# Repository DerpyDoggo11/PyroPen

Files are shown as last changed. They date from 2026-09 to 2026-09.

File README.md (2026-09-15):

# Pyropen
A pen with an embedded charlieplexed screen and thermal sensor

## 3D Model Preview
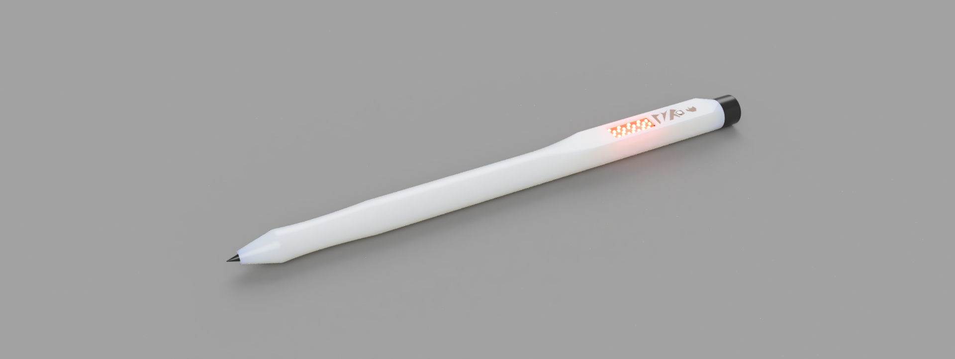
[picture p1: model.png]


## 3D PCB Preview
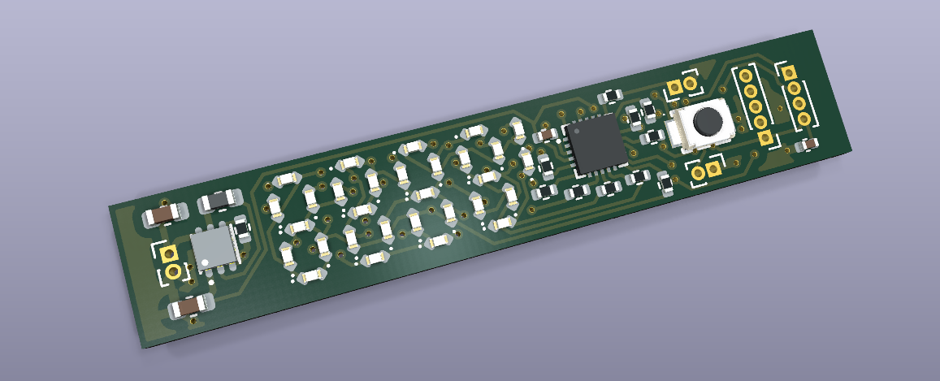
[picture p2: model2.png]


## Wiring
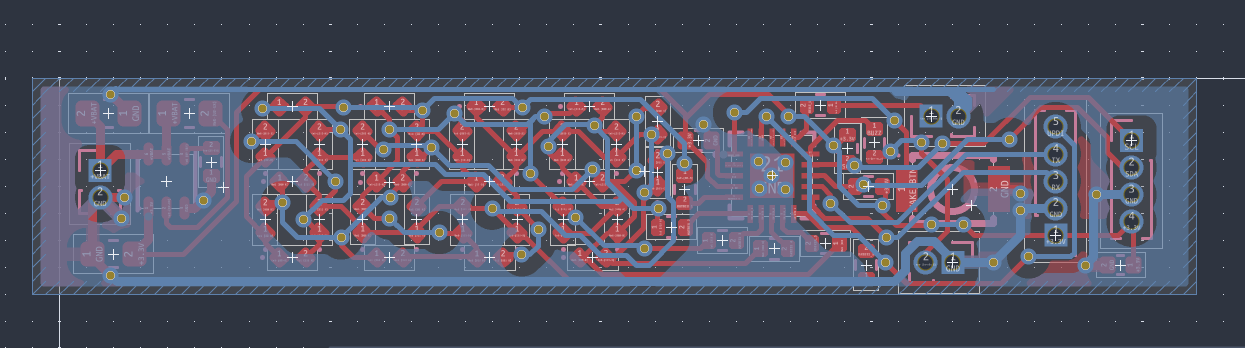
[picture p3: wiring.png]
PCB


## Schematic
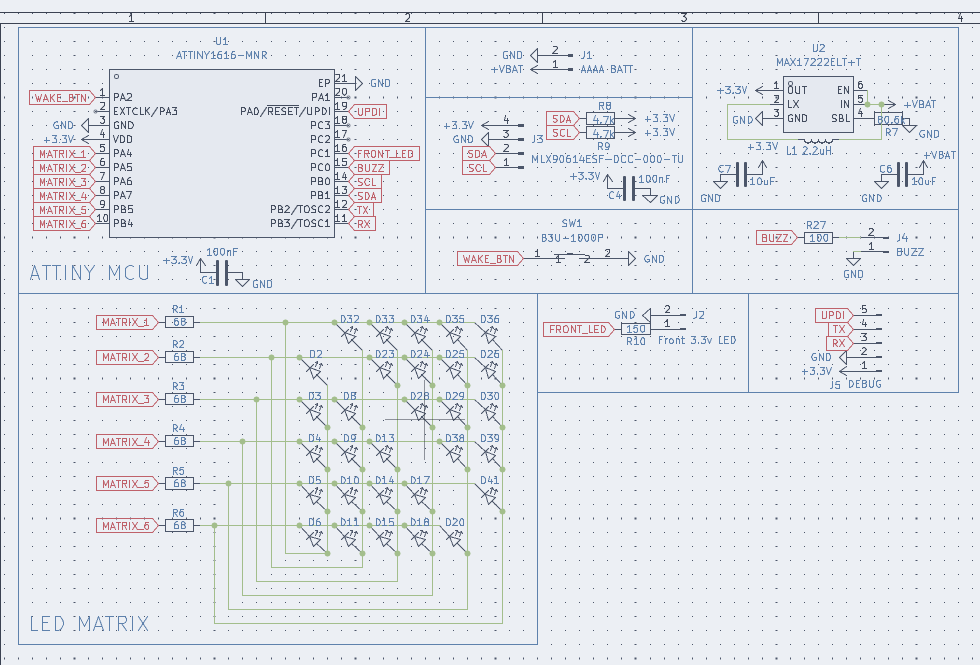
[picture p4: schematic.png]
Schematic


## Introduction
Hobby electronics projects can come with a lot of dangers, especially if there is a short between ground and the main voltage line (3.3v) through a component, which is one of the most common faults when hand soldering. These components can get really hot which means placing your finger to sense the temperature is not a super safe option, and is also not very possible for really small components in tight areas. Theres also hundreds of other applications like seeing if a soldering iron is at the good temperature or if something is being heated properly where touching it is not very recommended... 

My solution to this is the PyroPen - a portable thermal sensor that fits in the palm of your hand! It can also replace a regular pen, meaning that you have this sensor on you wherever you go. 

## Bill of Materials 

### 5 Pens:

| Quantity | Components | Price | Link |
|--- |---|---| -----|
| 5  | D1 Mini Pen Refill  (around 67mm long) | $6 | [here](https://www.aliexpress.us/item/3256810502408645.html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)
| 1 | Plexiglass sheet | $5 | [here](https://www.aliexpress.us/item/3256807722386926.html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)
| 1 | M10 tap and M10 die | $10-25 | [here](https://www.aliexpress.us/item/3256806490105856.html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)
| 1 | Black Silicone Sheet | $6 | [here](https://www.aliexpress.us/item/3256803477740534.html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)
| 10 | Contact Springs | $3 | [here](https://www.aliexpress.us/item/3256811981198202.html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) 
| 5 | 5mm Piezoelectric Buzzers | $1 | [here](https://www.lcsc.com/product-detail/C76871.html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) 
| 5 | MLX Infrared Sensors | $44 | [here](https://www.lcsc.com/product-detail/C3663116.html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)
| 5 | AAAA Batteries | $7 | [here](https://www.amazon.com/AmazonBasics-Everyday-Alkaline-Batteries-8-Pack/dp/B00LH3DTYS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)
| 5 | Warm Leds | $1 | [here](https://www.lcsc.com/product-detail/C5440675.html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) 
| 5 | PCBA for PyroPen | $60 | Uploaded PCB fabrication files to JLCPCB and assemble it. 
 
Total cost: **$157**

Cost per pen: **$31.4**

----

## Tools / Other parts:
- M10 Tap and Die (from BOM)
- Hot glue + hot glue gun (or super glue)
- Dremel
- Raspbbery Pi, or any other device that can be used to flash firmware to the ATTINY chip.
- 3D printer

## Assembly
1. 3D print the case and assembly 
2. Use the M10 Tap and Die to thread the three pieces at their corresponding places
3. Cut plexiglass and glue onto the screen case
4. Remove the tabs from the PCB with a dremel (required for meeting the PCBA size requirements)
5. Flash firmware to the PCB with a raspbbery pi (or other method)
6. Solder on the buzzer, MLX sensor, and contact springs to the PCB
7. Insert the assembly into the case.
8. Glue the PCB to the inside of the case with the screen facing out and the button in place
9. Insert the pen refill tightly into the case
10. Mount the remaining components into the case, insert battery, and seal

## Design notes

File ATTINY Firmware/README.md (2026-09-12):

# PyroPen firmware

C++ / PlatformIO firmware for the PyroPen — a pen-format non-contact IR
thermometer built around an **ATtiny1616** (tinyAVR 1-series).

## What it does
- Reads object temperature from the **MLX90614** IR sensor over I²C.
- Displays it as a left→right **bar** on the 30-LED charlieplexed panel
  (range `25–250 °C`, configurable in `src/main.cpp`).
- Warns when the target is hot (≥ 45 °C): lights the **front LED** and beeps.
- **Button** (PA2): short press toggles °C/°F, long press (≥0.8 s) mutes the buzzer.
- Prints readings on the serial port (115200 baud, TX=PB2).
- Runs a startup LED sweep so you can verify every dot after assembly.

## Pin map (from the KiCad netlist)
| Function | MCU pin(s) |
|---|---|
| Charlieplex rails | PA4 PA5 PA6 PA7 PB5 PB4 |
| I²C (MLX90614) | SDA=PB1, SCL=PB0 (addr 0x5A) |
| Buzzer (BTL) | PC1 + PC0 (anti-phase) |
| Front LED | PC2 |
| Button | PA2 (active-low, pullup) |
| Serial debug | TX=PB2, RX=PB3 |
| UPDI (program) | PA0 |

## Build & flash
The board is programmed over **UPDI** (single wire), not ISP/SPI. Any
serial-UPDI adapter works, including a **Raspberry Pi**.

### Wiring the programmer to the DEBUG header (J5, 1.0 mm pitch)
J5 pinout: `1=UPDI  2=GND  3=RX  4=TX  5=+3.3V` — check pins 4/5 on the board
before powering. For flashing you only need UPDI + GND (+ 3.3V if the pen
isn't otherwise powered).

Classic serial-UPDI adapter (USB-serial or Pi UART):
```
  TX ──[1 kΩ]──┬── UPDI (J5.1)
  RX ──────────┘
  GND ── GND (J5.2)
```

### Set your port, then upload
Edit `upload_port` in `platformio.ini`:
- Raspberry Pi GPIO UART: `/dev/serial0` (enable UART, disable the serial console)
- USB-serial on Linux: `/dev/ttyUSB0`
- Windows: `COM4`

```bash
pio run                 # build
pio run -t upload       # flash over UPDI
pio device monitor      # 115200 baud
```

## Notes
- Clock is the **10 MHz** internal oscillator: at 3.3 V (MAX17222 boost) the
  part is not rated for 20 MHz. Change `board_build.f_cpu` only if you raise Vcc.
- The buzzer is bridge-tied across PC0/PC1; the `beep()` routine drives them
  anti-phase for a louder tone. This is why the standard Arduino `tone()` isn't
  used (it drives a single pin).
- Display multiplexing is cooperative (in `loop()`), so no hardware timer is
  claimed and it can't collide with `millis()`/`tone()`.

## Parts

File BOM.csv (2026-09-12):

Item | Quantity | Component | Price | Link
1 | 5 | D1 Mini Pen Refill (around 67mm long) | $6 | https://www.aliexpress.us/item/3256810502408645.html
2 | 1 | Plexiglass sheet | $5 | https://www.aliexpress.us/item/3256807722386926.html
3 | 1 | M10 tap and M10 die | $10-25 | https://www.aliexpress.us/item/3256806490105856.html
4 | 1 | Black Silicone Sheet | $6 | https://www.aliexpress.us/item/3256803477740534.html
5 | 10 | Contact Springs | $3 | https://www.aliexpress.us/item/3256811981198202.html
6 | 5 | 5mm Piezoelectric Buzzers | $1 | https://www.lcsc.com/product-detail/C76871.html
7 | 5 | MLX Infrared Sensors | $44 | https://www.lcsc.com/product-detail/C3663116.html
8 | 5 | PCBA for PyroPen | $80

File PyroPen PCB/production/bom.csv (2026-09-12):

Designator | Footprint | Quantity | Value | LCSC Part #
C1, C4 | 0402 | 2 | 100nF
C6, C7 | 0603 | 2 | 10uF
D10, D11, D13, D14, D15, D17, D18, D2, D20, D23, D24, D25, D26, D28, D29, D3, D30, D32, D33, D34, D35, D36, D38, D39, D4, D41, D5, D6, D8, D9 | 0402 | 30 | LED_45deg
J1 | PinHeader_1x02_P1.00mm_Vertical | 1 | AAAA BATT
J2 | PinHeader_1x02_P1.00mm_Vertical | 1 | Front 3.3v LED
J3 | PinHeader_1x04_P1.00mm_Vertical | 1 | MLX90614ESF-DCC-000-TU
J4 | PinHeader_1x02_P1.00mm_Vertical | 1 | BUZZ
J5 | PinHeader_1x05_P1.00mm_Vertical | 1 | DEBUG
L1 | 0603 | 1 | 2.2uH
R1, R2, R3, R4, R5, R6 | 0402 | 6 | 68
R10 | 0402 | 1 | 150
R27, R28 | 0402 | 2 | 100
R7 | 0402 | 1 | 80.6k
R8, R9 | 0402 | 2 | 4.7k
SW1 | KEY-SMD_B3U-1000PM | 1 | B3U-1000P | C231329
U1 | QFN-20_L3.0-W3.0-P0.40-BL-EP1.7 | 1 | ATTINY1616-MNR | C507118
U2 | TDFN-6_L2.0-W2.0-P0.65-BL | 1 | MAX17222ELT+T | C1121854

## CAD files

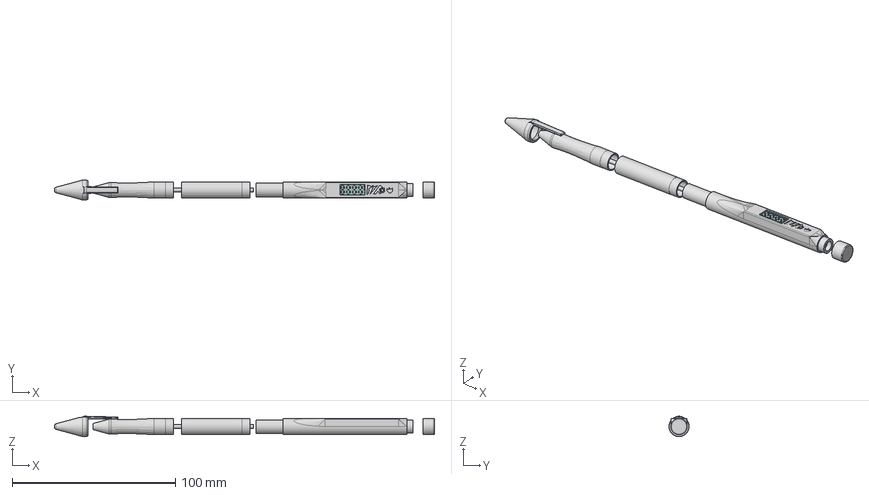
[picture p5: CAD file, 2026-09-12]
3D Case/pyropen-case.step
233.0 x 12.4 x 12.6 mm
LED_0402_1005Metric x 30
R_0402_1005Metric x 11
KEY-SMD_2P-L3.0-W2.5-H1.6-LS4.0
L_0603_1608Metric
TDFN-6_L2.0-W2.0-H0.8-P0.65-BL
QFN-20_L3.0-W3.0-P0.40-BL-EP1.7
C_0603_1608Metric x 2
C_0402_1005Metric x 2
AAAA Battery
Sensor

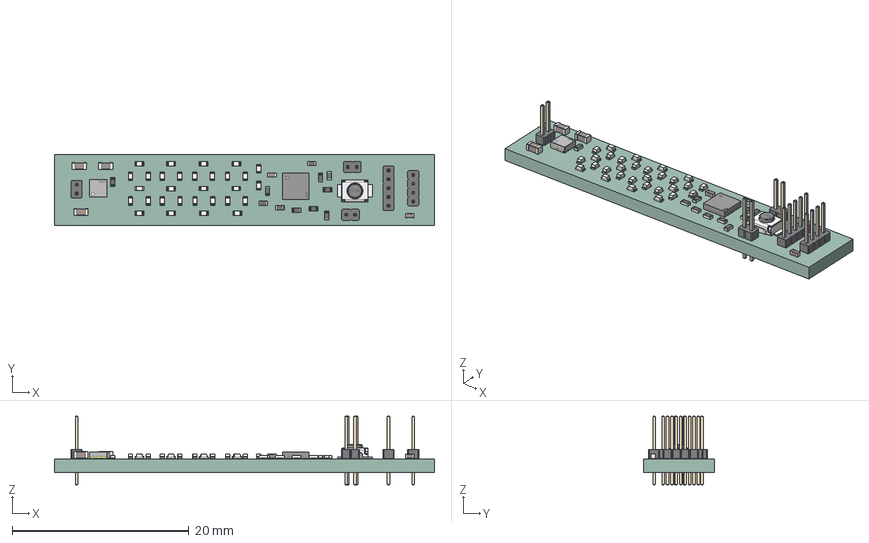
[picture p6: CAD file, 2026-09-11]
PyroPen PCB/pyropen.step
43.0 x 8.00 x 7.80 mm
LED_0402_1005Metric x 30
R_0402_1005Metric x 11
L_0603_1608Metric
TDFN-6_L2.0-W2.0-H0.8-P0.65-BL
PinHeader_1x02_P1.00mm_Vertical x 3
KEY-SMD_2P-L3.0-W2.5-H1.6-LS4.0
QFN-20_L3.0-W3.0-P0.40-BL-EP1.7
C_0402_1005Metric x 2
C_0603_1608Metric x 2
PinHeader_1x04_P1.00mm_Vertical
PinHeader_1x05_P1.00mm_Vertical
pyropen_PCB

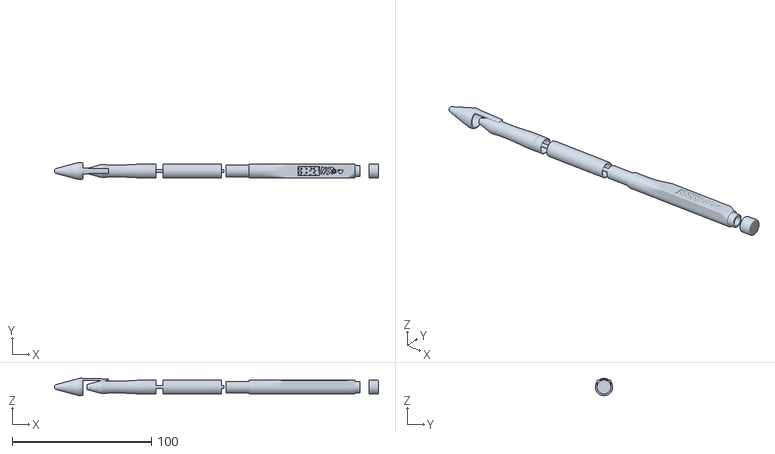
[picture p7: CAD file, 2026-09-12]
3D Case/pyropen.stl
233.0 x 12.5 x 12.6

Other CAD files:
3D Case/pyropen.f3d

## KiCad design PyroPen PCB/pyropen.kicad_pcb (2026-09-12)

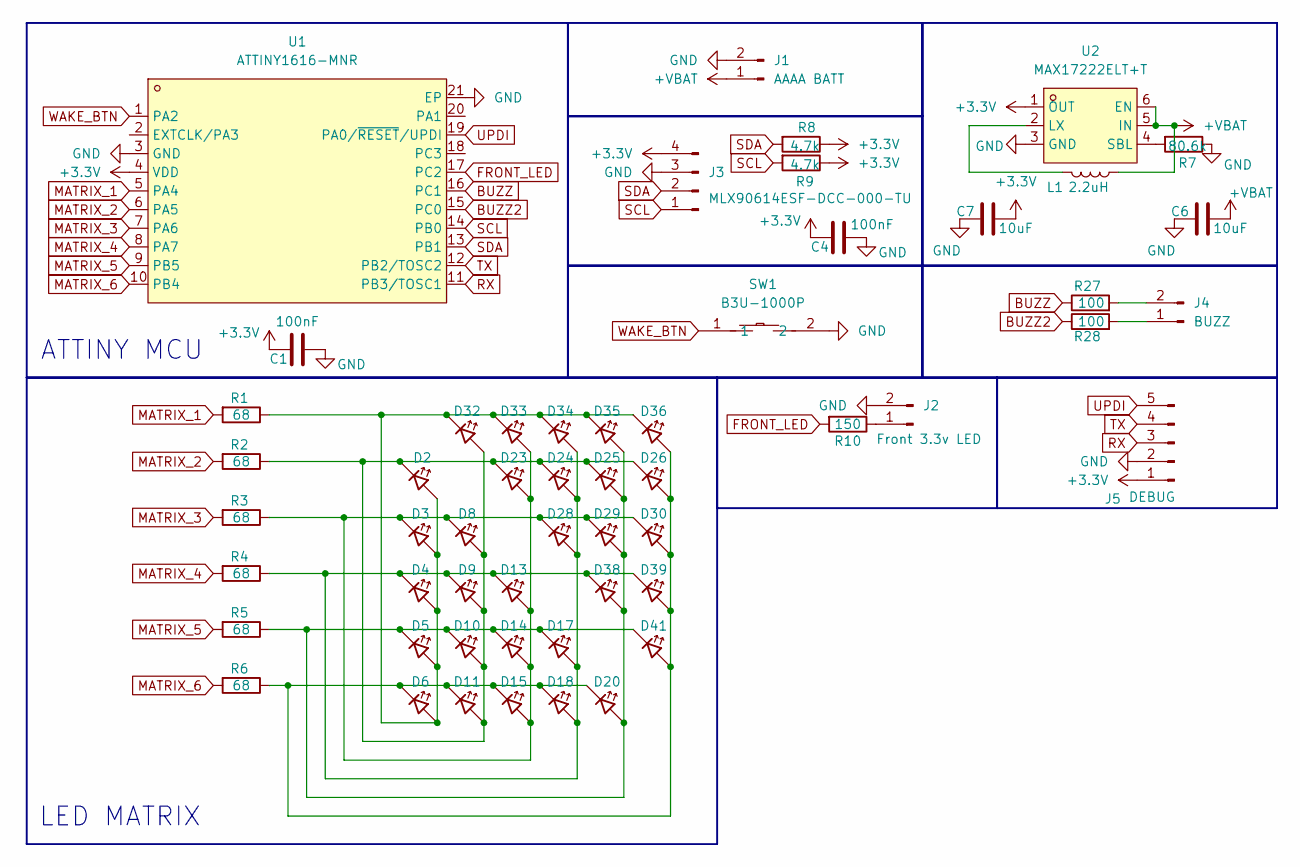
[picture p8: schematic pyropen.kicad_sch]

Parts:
C1, C4: 100nF; C_0402_1005Metric
C6, C7: 10uF; C_0603_1608Metric
D2, D3, D4, D5, D6, D8, D9, D10, D11, D13, D14, D15, D17, D18, D20, D23, D24, D25, D26, D28, D29, D30, D32, D33, D34, D35, D36, D38, D39, D41: LED_45deg; LED_0402_1005Metric
J1: AAAA BATT; PinHeader_1x02_P1.00mm_Vertical
J2: Front 3.3v LED; PinHeader_1x02_P1.00mm_Vertical
J3: MLX90614ESF-DCC-000-TU; PinHeader_1x04_P1.00mm_Vertical
J4: BUZZ; PinHeader_1x02_P1.00mm_Vertical
J5: DEBUG; PinHeader_1x05_P1.00mm_Vertical
L1: 2.2uH; L_0603_1608Metric
R1, R2, R3, R4, R5, R6: 68; R_0402_1005Metric
R7: 80.6k; R_0402_1005Metric
R8, R9: 4.7k; R_0402_1005Metric
R10: 150; R_0402_1005Metric
R27, R28: 100; R_0402_1005Metric
SW1: B3U-1000P; KEY-SMD_B3U-1000PM; MPN B3U-1000P; LCSC Part C231329
U1: ATTINY1616-MNR; QFN-20_L3.0-W3.0-P0.40-BL-EP1.7; MPN ATTINY1616-MNR; LCSC Part C507118
U2: MAX17222ELT+T; TDFN-6_L2.0-W2.0-P0.65-BL; MPN MAX17222ELT+T; LCSC Part C1121854

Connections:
+3.3V: C1.1, C4.1, C7.2, J3.4, J5.1, R8.1, R9.1, U1.4 (VDD), U2.1 (OUT)
+VBAT: C6.2, J1.1, L1.1, U2.5 (IN), U2.6 (EN)
BUZZ: R27.1, U1.16 (PC1)
BUZZ2: R28.1, U1.15 (PC0)
FRONT_LED: R10.2, U1.17 (PC2)
GND: C1.2, C4.2, C6.1, C7.1, J1.2, J2.2, J3.3, J5.2, R7.1, SW1.2, U1.3 (GND), U1.21 (EP), U2.3 (GND)
MATRIX_1: R1.2, U1.5 (PA4)
MATRIX_2: R2.2, U1.6 (PA5)
MATRIX_3: R3.2, U1.7 (PA6)
MATRIX_4: R4.2, U1.8 (PA7)
MATRIX_5: R5.2, U1.9 (PB5)
MATRIX_6: R6.2, U1.10 (PB4)
unnamed: D2.2 (A), D3.2 (A), D4.2 (A), D5.2 (A), D6.2 (A), D32.1 (K), D33.1 (K), D34.1 (K), D35.1 (K), D36.1 (K), R1.1
unnamed: D2.1 (K), D8.2 (A), D9.2 (A), D10.2 (A), D11.2 (A), D23.1 (K), D24.1 (K), D25.1 (K), D26.1 (K), D32.2 (A), R2.1
unnamed: D5.1 (K), D10.1 (K), D14.1 (K), D17.1 (K), D20.2 (A), D25.2 (A), D29.2 (A), D35.2 (A), D38.2 (A), D41.1 (K), R5.1
unnamed: D6.1 (K), D11.1 (K), D15.1 (K), D18.1 (K), D20.1 (K), D26.2 (A), D30.2 (A), D36.2 (A), D39.2 (A), D41.2 (A), R6.1
unnamed: D3.1 (K), D8.1 (K), D13.2 (A), D14.2 (A), D15.2 (A), D23.2 (A), D28.1 (K), D29.1 (K), D30.1 (K), D33.2 (A), R3.1
unnamed: D4.1 (K), D9.1 (K), D13.1 (K), D17.2 (A), D18.2 (A), D24.2 (A), D28.2 (A), D34.2 (A), D38.1 (K), D39.1 (K), R4.1
unnamed: J2.1, R10.1
unnamed: J4.1, R28.2
unnamed: J4.2, R27.2
unnamed: L1.2, U2.2 (LX)
unnamed: R7.2, U2.4 (SBL)
RX: J5.3, U1.11 (PB3/TOSC1)
SCL: J3.1, R9.2, U1.14 (PB0)
SDA: J3.2, R8.2, U1.13 (PB1)
TX: J5.4, U1.12 (PB2/TOSC2)
UPDI: J5.5, U1.19 (PA0/~RESET/UPDI)
WAKE_BTN: SW1.1, U1.1 (PA2)

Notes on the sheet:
LED MATRIX
ATTINY MCU

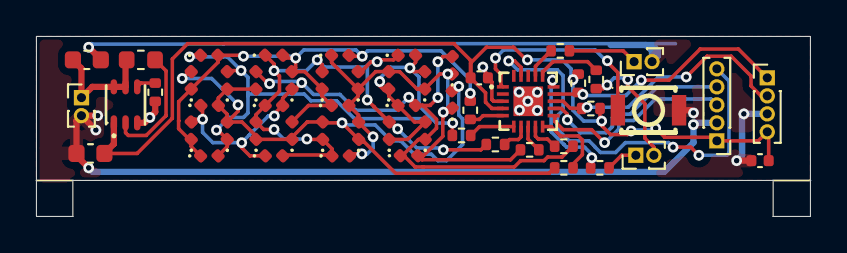
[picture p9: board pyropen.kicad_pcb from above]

Board: 2 copper layers, 43.0 x 10.0 mm, 55 parts (0 on the bottom side), 29 nets.

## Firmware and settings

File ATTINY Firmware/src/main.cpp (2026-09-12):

// ============================================================================
//  PyroPen firmware
//  MCU : ATtiny1616 @ 10 MHz internal (3.3V), megaTinyCore
//
//  A pen-format non-contact thermometer: an MLX90614 IR sensor reads the
//  object temperature, which is shown as a left->right bar on a 30-LED
//  charlieplexed display. A piezo buzzer and a front LED warn when the
//  target is hot. A single button toggles the temperature unit (short press)
//  and mutes the buzzer (long press).
//
//  Hardware map (from the KiCad schematic/PCB netlist):
//    Charlieplex rails : PA4 PA5 PA6 PA7 PB5 PB4   (MATRIX_1..6, via R1..R6)
//    IR sensor (I2C)   : SDA=PB1  SCL=PB0          (MLX90614 on J3, addr 0x5A)
//    Buzzer (BTL)      : PC1 (BUZZ) + PC0 (BUZZ2)  (piezo across J4)
//    Front LED         : PC2                        (via R10 -> J2, active high)
//    Button            : PA2  (to GND, active low)
//    Serial debug      : TX=PB2  RX=PB3  @115200
// ============================================================================

#include <Arduino.h>
#include <Wire.h>
#include <Adafruit_MLX90614.h>

// ----------------------------------------------------------------------------
// Pins
// ----------------------------------------------------------------------------
static const uint8_t PIN_FRONT_LED = PIN_PC2;
static const uint8_t PIN_BUTTON    = PIN_PA2;
static const uint8_t PIN_BUZZ_A    = PIN_PC1;   // BUZZ
static const uint8_t PIN_BUZZ_B    = PIN_PC0;   // BUZZ2 (driven anti-phase)

// ----------------------------------------------------------------------------
// Charlieplex display: 6 rails, 30 LEDs (fully populated).
// The panel is an irregular dot cloud, so LEDs are ordered here by their
// physical X position: index 0 = leftmost dot ... 29 = rightmost. That makes
// a temperature "bar" as simple as lighting indices 0..n-1.
// LED_AC[i] = {anode rail, cathode rail}. Rails: 0=PA4 1=PA5 2=PA6 3=PA7 4=PB5 5=PB4
// ----------------------------------------------------------------------------
#define NUM_RAILS 6
#define NUM_LEDS  30

static const uint8_t LED_AC[NUM_LEDS][2] = {
  {5,0}, // [ 0] D36
  {4,0}, // [ 1] D35
  {0,1}, // [ 2] D2
  {5,4}, // [ 3] D41
  {1,0}, // [ 4] D32
  {1,5}, // [ 5] D11
  {5,1}, // [ 6] D26
  {4,5}, // [ 7] D20
  {2,5}, // [ 8] D15
  {0,2}, // [ 9] D3
  {4,2}, // [10] D29
  {2,4}, // [11] D14
  {0,4}, // [12] D5
  {0,5}, // [13] D6
  {2,0}, // [14] D33
  {5,2}, // [15] D30
  {0,3}, // [16] D4
  {3,0}, // [17] D34
  {3,2}, // [18] D28
  {2,3}, // [19] D13
  {3,5}, // [20] D18
  {3,1}, // [21] D24
  {2,1}, // [22] D23
  {1,2}, // [23] D8
  {4,1}, // [24] D25
  {3,4}, // [25] D17
  {1,3}, // [26] D9
  {1,4}, // [27] D10
  {4,3}, // [28] D38
  {5,3}, // [29] D39
};

// Direct-port descriptors for each rail (fast, glitch-free multiplexing).
// PA4..PA7 live on PORTA bits 4..7; PB4/PB5 on PORTB bits 4/5.
struct RailIO { PORT_t* port; uint8_t bm; };
static RailIO rail[NUM_RAILS] = {
  { &PORTA, PIN4_bm }, // rail0 PA4
  { &PORTA, PIN5_bm }, // rail1 PA5
  { &PORTA, PIN6_bm }, // rail2 PA6
  { &PORTA, PIN7_bm }, // rail3 PA7
  { &PORTB, PIN5_bm }, // rail4 PB5
  { &PORTB, PIN4_bm }, // rail5 PB4
};
static const uint8_t PORTA_RAIL_MASK = PIN4_bm | PIN5_bm | PIN6_bm | PIN7_bm;
static const uint8_t PORTB_RAIL_MASK = PIN4_bm | PIN5_bm;

// Frame buffer: one bit per LED.
static uint32_t frame = 0;

static inline void railsAllHiZ() {
  // Set every rail pin back to input (Hi-Z). Leaves PB0..PB3 (I2C/serial) alone.
  PORTA.DIRCLR = PORTA_RAIL_MASK;
  PORTB.DIRCLR = PORTB_RAIL_MASK;
}

static inline void lightPair(uint8_t a, uint8_t c) {
  railsAllHiZ();
  rail[a].port->OUTSET = rail[a].bm;  // anode high
  rail[a].port->DIRSET = rail[a].bm;
  rail[c].port->OUTCLR = rail[c].bm;  // cathode low
  rail[c].port->DIRSET = rail[c].bm;
}

// Display timing: 30 equal slots keep brightness uniform regardless of how
// many LEDs are on. ~250us/slot -> ~7.5ms/frame -> ~130 Hz (flicker-free).
static const uint16_t SLOT_US = 250;

// Render one full frame, then park the display Hi-Z.
static void renderFrame() {
  for (uint8_t i = 0; i < NUM_LEDS; i++) {
    if (frame & ((uint32_t)1 << i)) {
      lightPair(LED_AC[i][0], LED_AC[i][1]);
    } else {
      railsAllHiZ();
    }
    delayMicroseconds(SLOT_US);
  }
  railsAllHiZ();
}

// Show 'n' LEDs as a bar from the left.
static void setBar(uint8_t n) {
  if (n > NUM_LEDS) n = NUM_LEDS;
  frame = (n >= 32) ? 0xFFFFFFFFul : (((uint32_t)1 << n) - 1);
}

// ----------------------------------------------------------------------------
// Buzzer: piezo is wired across PC1/PC0. Driving them anti-phase gives a
// bridge-tied load (roughly double the voltage swing) for a louder beep.
// Blocking, so keep beeps short.
// ----------------------------------------------------------------------------
static void beep(uint16_t freqHz, uint16_t ms) {
  if (freqHz == 0 || ms == 0) return;
  pinMode(PIN_BUZZ_A, OUTPUT);
  pinMode(PIN_BUZZ_B, OUTPUT);
  uint32_t halfUs   = 500000UL / freqHz;
  uint32_t cycles   = (uint32_t)ms * 1000UL / (halfUs * 2);
  for (uint32_t i = 0; i < cycles; i++) {
    digitalWrite(PIN_BUZZ_A, HIGH); digitalWrite(PIN_BUZZ_B, LOW);
    delayMicroseconds(halfUs);
    digitalWrite(PIN_BUZZ_A, LOW);  digitalWrite(PIN_BUZZ_B, HIGH);
    delayMicroseconds(halfUs);
  }
  // Rest both terminals low so the piezo isn't left charged.
  digitalWrite(PIN_BUZZ_A, LOW);
  digitalWrite(PIN_BUZZ_B, LOW);
}

// ----------------------------------------------------------------------------
// Application state
// ----------------------------------------------------------------------------
Adafruit_MLX90614 mlx = Adafruit_MLX90614();

static bool  sensorOK   = false;
static bool  useFahren  = false;   // false = Celsius (short-press toggles)
static bool  buzzerMute = false;   // long-press toggles

// Bar range (object temperature in Celsius): tuned for soldering/heat work.
static const float TEMP_MIN_C = 25.0f;
static const float TEMP_MAX_C = 250.0f;
// Warning threshold: at/above this the front LED lights and it beeps.
static const float HOT_C      = 45.0f;

// ----------------------------------------------------------------------------
// Button: short press < 800ms -> toggle unit; long press -> toggle mute.
// Non-blocking, sampled once per frame.
// ----------------------------------------------------------------------------
static bool     btnPrev      = false;
static uint32_t btnDownAt    = 0;
static bool     btnLongFired = false;
static const uint16_t LONG_MS = 800;

static void pollButton() {
  bool down = (digitalRead(PIN_BUTTON) == LOW);   // active low
  uint32_t now = millis();

  if (down && !btnPrev) {                 // press edge
    btnDownAt = now;
    btnLongFired = false;
  } else if (down && btnPrev) {           // held
    if (!btnLongFired && (now - btnDownAt) >= LONG_MS) {
      buzzerMute = !buzzerMute;
      btnLongFired = true;
      if (!buzzerMute) beep(2000, 40);    // confirm un-mute audibly
    }
  } else if (!down && btnPrev) {          // release edge
    if (!btnLongFired && (now - btnDownAt) >= 30) {  // debounced short press
      useFahren = !useFahren;
      beep(2500, 25);
    }
  }
  btnPrev = down;
}

// ----------------------------------------------------------------------------
// Startup sweep: chase the bar left->right so a builder can confirm every
// rail and LED works right after flashing.
// ----------------------------------------------------------------------------
static void startupSweep() {
  for (uint8_t i = 0; i < NUM_LEDS; i++) {
    frame = ((uint32_t)1 << i);
    for (uint8_t r = 0; r < 3; r++) renderFrame();   // ~22ms per dot
  }
  frame = 0;
}

// ----------------------------------------------------------------------------
void setup() {
  pinMode(PIN_FRONT_LED, OUTPUT);
  digitalWrite(PIN_FRONT_LED, LOW);
  pinMode(PIN_BUTTON, INPUT_PULLUP);
  pinMode(PIN_BUZZ_A, OUTPUT);
  pinMode(PIN_BUZZ_B, OUTPUT);
  digitalWrite(PIN_BUZZ_A, LOW);
  digitalWrite(PIN_BUZZ_B, LOW);
  railsAllHiZ();

  Serial.begin(115200);
  Serial.println(F("PyroPen boot"));

  Wire.begin();
  sensorOK = mlx.begin();               // default I2C addr 0x5A
  Serial.println(sensorOK ? F("MLX90614 OK") : F("MLX90614 NOT FOUND"));

  beep(2000, 30);
  startupSweep();
}

// ----------------------------------------------------------------------------
void loop() {
  static uint32_t lastRead = 0;
  static float    objC     = NAN;
  static uint32_t lastBeep = 0;

  // Read the sensor a few times per second (blocking read is a few ms; it
  // briefly pauses the display, which is imperceptible at this cadence).
  uint32_t now = millis();
  if (sensorOK && (now - lastRead) >= 200) {
    lastRead = now;
    objC = mlx.readObjectTempC();

    float shown = useFahren ? (objC * 9.0f / 5.0f + 32.0f) : objC;
    Serial.print(F("obj="));
    Serial.print(shown, 1);
    Serial.println(useFahren ? F(" F") : F(" C"));
  }

  // --- map temperature to bar + warnings ---
  if (!sensorOK || isnan(objC)) {
    // Error: flash the two end LEDs, no bar.
    frame = (uint32_t)1 | ((uint32_t)1 << (NUM_LEDS - 1));
    if ((now / 300) & 1) frame = 0;
    digitalWrite(PIN_FRONT_LED, LOW);
  } else {
    float t = objC;
    int n = (int)((t - TEMP_MIN_C) / (TEMP_MAX_C - TEMP_MIN_C) * NUM_LEDS + 0.5f);
    if (t > TEMP_MIN_C && n < 1) n = 1;   // show at least one dot once above floor
    if (n < 0) n = 0;
    setBar((uint8_t)n);

    bool hot = (t >= HOT_C);
    digitalWrite(PIN_FRONT_LED, hot ? HIGH : LOW);
    if (hot && !buzzerMute && (now - lastBeep) >= 1500) {
      lastBeep = now;
      beep(3200, 60);
    }
  }

  pollButton();
  renderFrame();
}
